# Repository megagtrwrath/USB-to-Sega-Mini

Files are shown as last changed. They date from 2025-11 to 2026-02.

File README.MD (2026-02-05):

# USB to Sega Mini
A Controller adapter for the Sega Saturn, MegaDrive and Genesis!

***Built on [Sonik-br's](https://github.com/sonik-br) USB2RetroConsole firmware***
Link to the firmware ***[HERE!](https://github.com/sonik-br/usb2retroconsole-fw)***

You can get a pre-built copy of the firmware for this board [here!](https://cdn.discordapp.com/attachments/704047253282619503/1441765426223775895/usb2saturn.waveshare_rp2040_zero_mega03_20251122.uf2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) (Saturn only for now) 

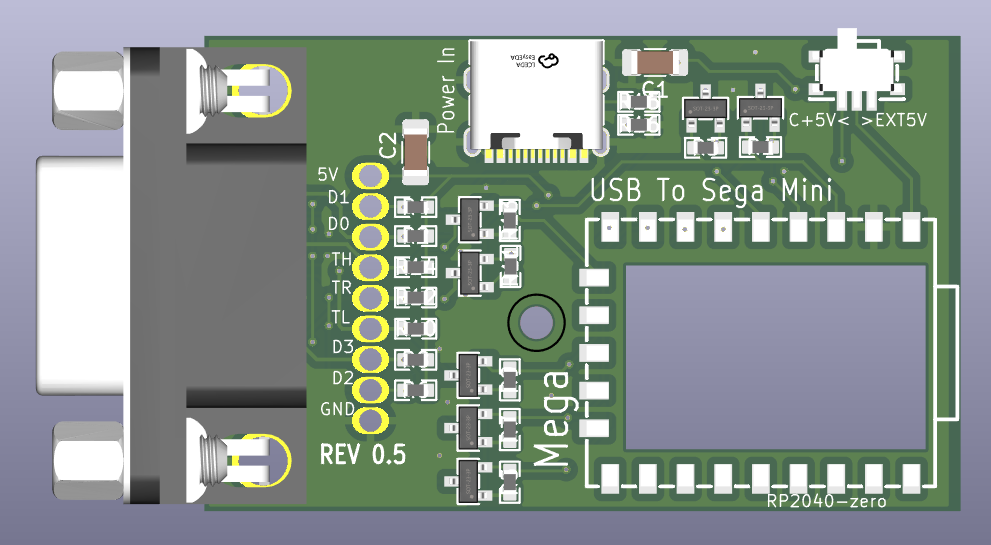
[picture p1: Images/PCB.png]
Project Image


## About this project
This github repo includes the source KICAD files for making modifications, and has it's GERBER, BOM and CPL in the Production Files folder. You may need to make modifications to find suitable parts
I have manually excluded the DB9 connector and Saturn connector as to freely allow installation of whichever you choose.

## Features:
<ul>
	<li>Support for various wired controllers (Original Xbox, 360, One, Series, PS3, PS4, PS5, Switch and any XINPUT capable device</li>
	<li>Low latency conversion, under or around 1 frame</li>
	<li>Emulation of various controllers (3D Pad [Digital and Analog modes], Arcade Racer/Steering Wheel, Mission Stick (3 axis mode), Shuttle mouse)</li>
	<li>Plug and play! No console modification required!</li>
	<li>Optional external USB power for power hungry controllers!</li>
</ul>

## To Do:
<ul>
	<li>3d printed case</li>
	<li>Further design optimizations</li>
	<li>Better documentation</li>
</ul>

## License
Copyright © 2025 Mega

This project is licensed under the **CERN-OHL-S V2** license.

This means you can:
<ul>
	<li>Use and reproduce this adapter for any purpose</li>
	<li>Make modifications to better fit your requirements</li>
	<li>Distribute this design, or any modifications you make to this design</li>
</ul>
This also requires that you:
<ul>
	<li>Give credit to the original board design</li>
	<li>Share your modifications under the exact same CERN-OHL-S V2 license</li>
	<li>Keep all copyright and licenses intact, this includes any original markings on the PCB, Logos and Project URLs present in the files. These ***cannot be removed or altered*** </lil>
<ul>

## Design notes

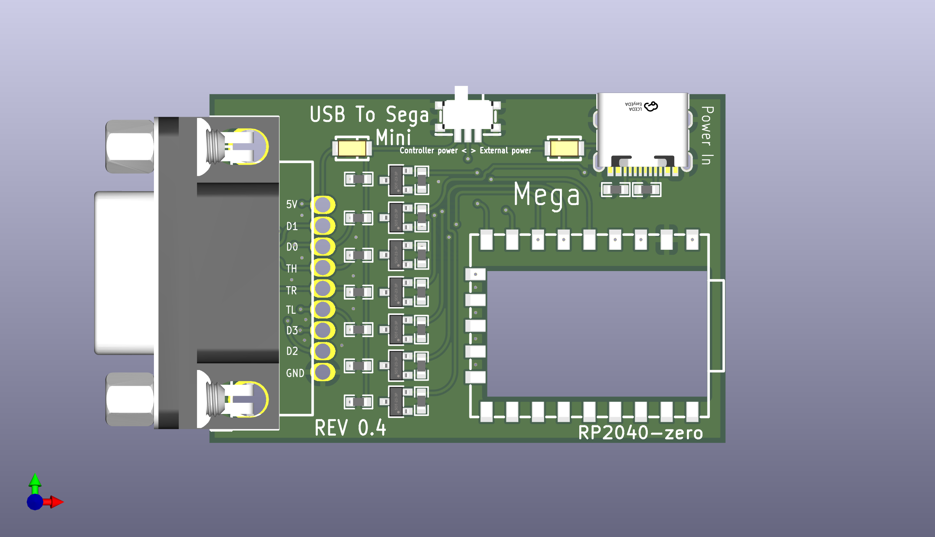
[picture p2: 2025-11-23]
Images/ProPrj_SaturnAdapter_2025-11-23.png

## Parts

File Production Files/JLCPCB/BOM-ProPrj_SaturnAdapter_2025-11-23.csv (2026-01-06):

Comment | Designator | Footprint | LCSC | Quantity
 | USB-1 | USB-C_SMD-TYPE-C-31-M-12_1 | C165948 | 1
10k | R1,R10,R11,R12,R13,R14,R2,R3,R4,R5,R6,R7,R8,R9 | R0603 | C25804 | 14
10uF | C1,C2 | C_1206_3216Metric_Pad1.33x1.80mm_HandSolder | C13585 | 2
5.1k | R15,R16 | R0603 | C23186 | 2
BSS138B | Q1,Q2,Q3,Q4,Q5,Q6,Q7 | SOT-23-3_L2.9-W1.3-P1.90-LS2.4-BR | C20599939 | 7
MINI MSK12CO2 | SW1 | SW-SMD_MSK12CO2 | C2681570 | 1
~ | U2 | SATURN CONNECTOR |  | 1
RP2040-Zero | U3 | COMM-SMD_RP2040-ZERO |  | 1

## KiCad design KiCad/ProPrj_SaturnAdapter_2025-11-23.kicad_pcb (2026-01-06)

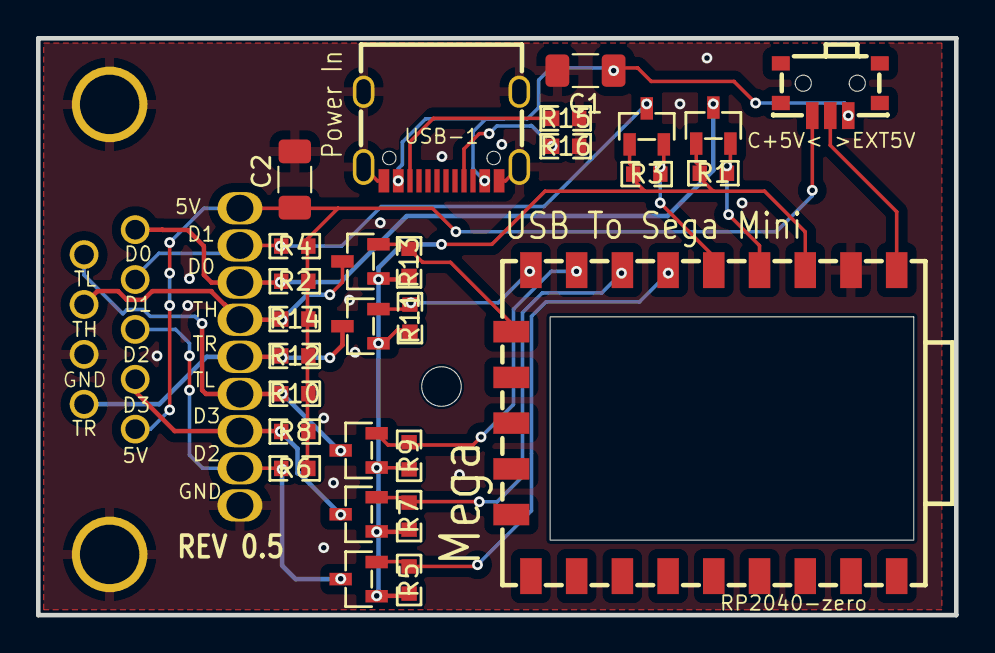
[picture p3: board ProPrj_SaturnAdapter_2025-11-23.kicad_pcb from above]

Board: 2 copper layers, 51.0 x 32.0 mm, 30 parts (0 on the bottom side), 21 nets.

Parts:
C1, C2: 10uF; C_1206_3216Metric_Pad1.33x1.80mm_HandSolder
CN1: DSUB-TH_FDB0901-M0DB300K6KF
Q1, Q2, Q3, Q4, Q5, Q6, Q7: BSS138B; SOT-23-3_L2.9-W1.3-P1.90-LS2.4-BR
R1, R2, R3, R4, R5, R6, R7, R8, R9, R10, R11, R12, R13, R14: 10k; R0603
R15, R16: 5.1k; R0603
SW1: MINI MSK12CO2; SW-SMD_MSK12CO2
U2: SATURN CONNECTOR
U3: RP2040-Zero; COMM-SMD_RP2040-ZERO
USB-1: USB-C_SMD-TYPE-C-31-M-12_1

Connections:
C+5V: C2.1, CN1.5, R2.2, R4.1, R6.2, R8.2, R10.2, R12.2, R14.2, SW1.3, U2.1
D0: CN1.1, Q1.3 (D), R2.1, U2.3
D1: CN1.2, Q2.3 (D), R4.2, U2.2
D2: CN1.3, Q3.3 (D), R6.1, U2.8
D3: CN1.4, Q4.3 (D), R8.1, U2.7
EXT5V: C1.1, SW1.1, USB-1.A4B9, USB-1.B4A9
GND: C1.2, C2.2, CN1.8, CN1.10, CN1.11, R15.1, R16.1, SW1.4, SW1.5, U2.9, U3.22 (GND), USB-1.1, USB-1.2, USB-1.3, USB-1.4, USB-1.A1B12, USB-1.B1A12
LO_D0: Q1.2 (S), R1.1, U3.20 (GP29)
LO_D1: Q2.2 (S), R3.2, U3.19 (GP28)
LO_D2: Q3.2 (S), R5.1, U3.18 (GP27)
LO_D3: Q4.2 (S), R7.1, U3.17 (GP26)
LO_TH: Q7.2 (S), R13.1, U3.14 (GP13)
LO_TL: Q5.2 (S), R9.1, U3.16 (GP15)
LO_TR: Q6.2 (S), R11.1, U3.15 (GP14)
MINI+5V: SW1.2, U3.23 (5V)
unnamed: R16.2, USB-1.A5
unnamed: R15.2, USB-1.B5
TH: CN1.7, Q7.3 (D), R14.1, U2.4
TL: CN1.6, Q5.3 (D), R10.1, U2.6
TR: CN1.9, Q6.3 (D), R12.1, U2.5
VCC: Q1.1 (G), Q2.1 (G), Q3.1 (G), Q4.1 (G), Q5.1 (G), Q6.1 (G), Q7.1 (G), R1.2, R3.1, R5.2, R7.2, R9.2, R11.2, R13.2, U3.21 (3V3)

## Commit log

2025-11-23 Initial commit - REV0.4 board
    [ProPrj_SaturnAdapter_2025-11-23.kicad_pcb, ProPrj_SaturnAdapter_2025-11-23.kicad_sch]
2025-11-23 Updated PCB to mark certain components as not to populated (DB9,Saturn port, RP2040-Zero)
    [ProPrj_SaturnAdapter_2025-11-23.kicad_pcb]
2025-11-23 Rev 0.5 changes | Moving of USB C port next to DB-9/MD connector
    [ProPrj_SaturnAdapter_2025-11-23.kicad_pcb]
2025-11-24 Revert "Updated PCB to mark certain components as not to populated (DB9,Saturn port, RP2040-Zero)"
    This reverts commit e9491987f3115d9c6acc2593fec8dd3ece14de18.
    [ProPrj_SaturnAdapter_2025-11-23.kicad_pcb]
2025-11-24 Revert "Rev 0.5 changes | Moving of USB C port next to DB-9/MD connector"
    This reverts commit 421da58faffa196843ed661754ba694fad0c3bff.
    [ProPrj_SaturnAdapter_2025-11-23.kicad_pcb]
2025-11-24 REV0.5 - Moved USB port next to controller port
    [ProPrj_SaturnAdapter_2025-11-23.kicad_pcb]
2025-11-24 REV0.5 - Make RP2040, DB9 and Saturn socket not part of BOM and Placement files
    [ProPrj_SaturnAdapter_2025-11-23.kicad_pcb]
2025-11-24 REV0.5 - Move USB and Switch around, shrink board size to more closely match REV0.4
    [ProPrj_SaturnAdapter_2025-11-23.kicad_pcb]
2025-11-25 REV0.5 - Moved two of the SOT-23-3Ps to make room for a further shifting of the USB C port towards the controller plug
    [ProPrj_SaturnAdapter_2025-11-23.kicad_pcb]
2025-11-25 Further adjustment of USB port placement and trace optimisation (All curved traces replaced with 45 degrees)
    [ProPrj_SaturnAdapter_2025-11-23.kicad_pcb]
2025-11-25 Add mounting holes for eventual 3d printed case
    [ProPrj_SaturnAdapter_2025-11-23.kicad_pcb]
2025-11-25 Add Change to central mounting hole for future case
    [ProPrj_SaturnAdapter_2025-11-23.kicad_pcb]
2025-11-26 Updated schematic for neatness, and further shrank the PCB with the USB-C port brought closer to center
    [ProPrj_SaturnAdapter_2025-11-23.kicad_pcb, ProPrj_SaturnAdapter_2025-11-23.kicad_sch]
2025-11-27 Final alterations before prototype ordering
2025-12-09 Fix capacitors (Had it in line with the 5v rail rather than properly smoothing [facepalm ]
    [ProPrj_SaturnAdapter_2025-11-23.kicad_pcb, ProPrj_SaturnAdapter_2025-11-23.kicad_sch]
2025-12-28 Edits to files to facilitate prototype production, incl. gerbers.
    [BOM-ProPrj_SaturnAdapter_2025-11-23.csv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]
2025-12-29 Price optimisation by changing of certain components from the Extended LCSC set to the JLCPCB Basic set + minor changes
    [ProPrj_SaturnAdapter_2025-11-23.kicad_pcb, ProPrj_SaturnAdapter_2025-11-23.kicad_sch]
2025-12-29 Updated Production files with prior changes
    [BOM-ProPrj_SaturnAdapter_2025-11-23.csv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]
2026-02-05 README - Device emulation clarification
